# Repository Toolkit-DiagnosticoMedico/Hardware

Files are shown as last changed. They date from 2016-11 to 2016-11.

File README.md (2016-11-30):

# Hardware
Diseño de un Sistema Modular que permitirá medir magnitudes físicas relacionadas a la salud del paciente con la finalidad de
“subirlos la nube” para acceso de diversos servicios. Los parámetros a medir que se manejarán en ésta primera versión serán 
la temperatura, el pulso cardiaco, la presión arterial y la cantidad de la glucosa en la sangre.

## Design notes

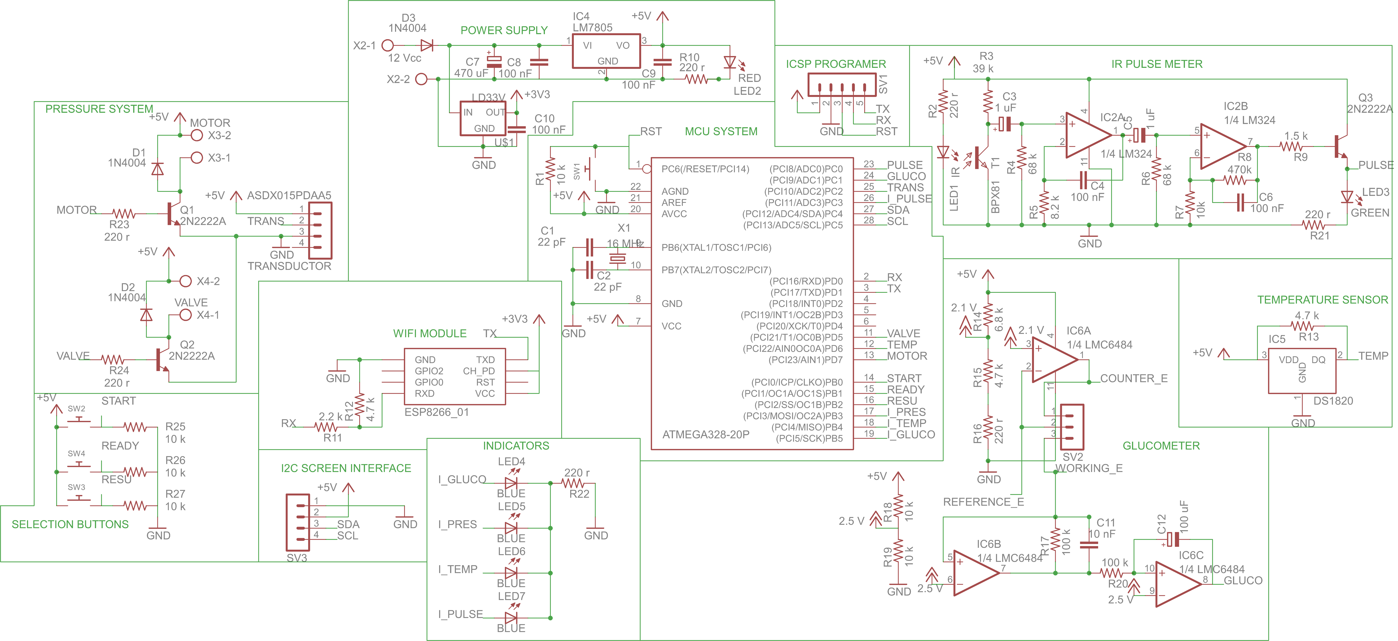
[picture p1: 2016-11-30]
DIAGRAMA.png

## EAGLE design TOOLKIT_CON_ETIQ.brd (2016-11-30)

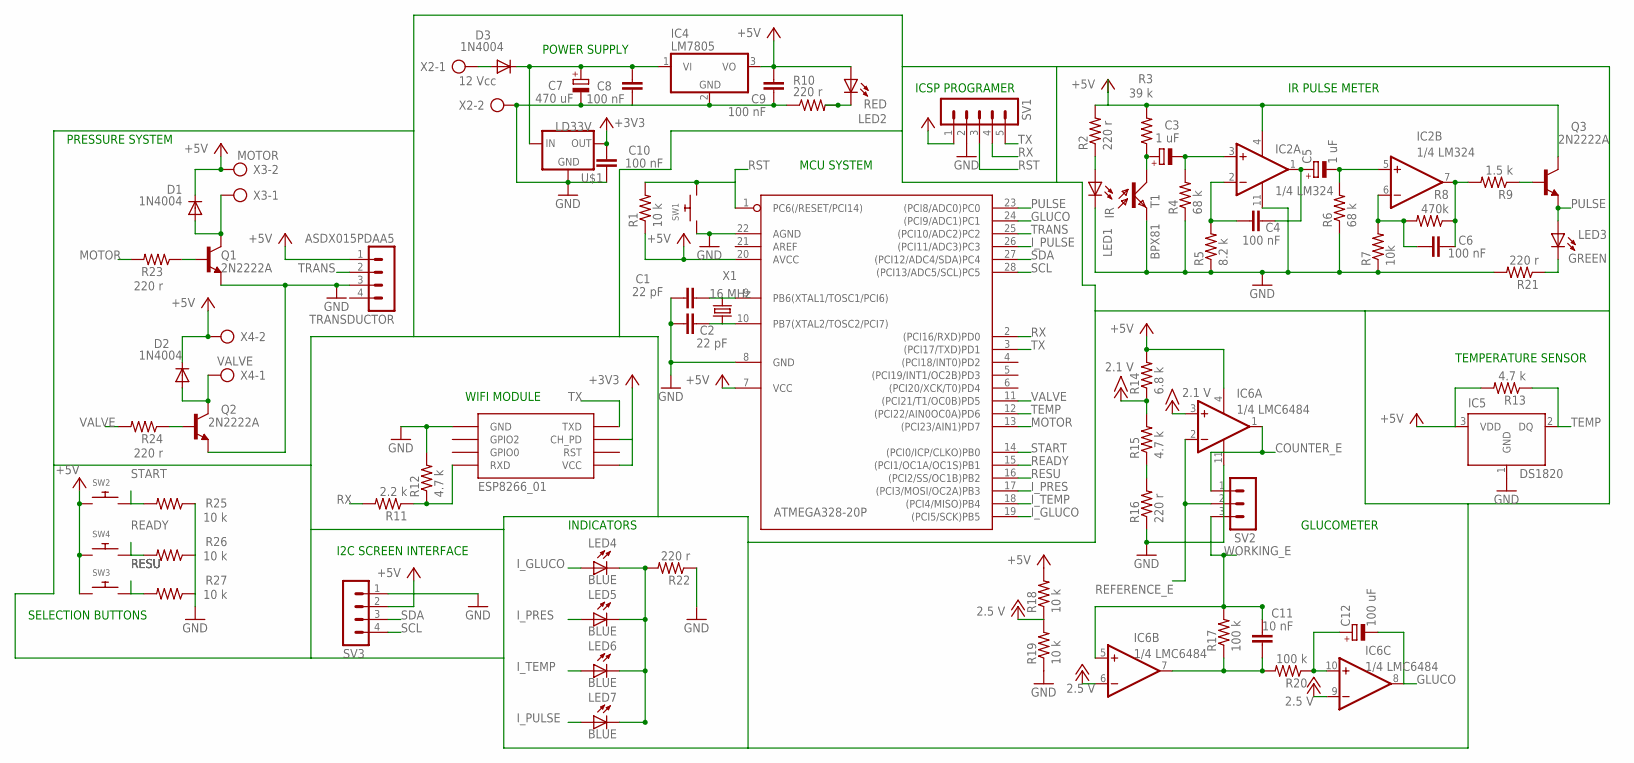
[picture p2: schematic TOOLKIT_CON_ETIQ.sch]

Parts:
C1, C2: 22 pF; C050-024X044
C3, C5: 1 uF; E2,5-6E
C4, C6, C8, C9, C10: 100 nF; C050-025X075
C7: 470 uF; E2,5-6E
C11: 10 nF; C050-025X075
C12: 100 uF; E2,5-6E
D1, D2, D3: 1N4004; DO41-10
IC1: ATMEGA328-20P; DIL28-3
IC2: 1/4 LM324; DIL14
IC4: LM7805; TO220V
IC5: DS1820; TO-92
IC6: 1/4 LMC6484; DIL14
LED1: IR; LED3MM
LED2: RED; LED3MM
LED3: GREEN; LED3MM
LED4, LED5, LED6, LED7: BLUE; LED3MM
Q1, Q2, Q3: 2N2222A; TO92-EBC
R1, R18, R19, R25, R26, R27: 10 k; 0207/10
R2, R10, R16, R21, R22, R23, R24: 220 r; 0207/10
R3: 39 k; 0207/10
R4, R6: 68 k; 0207/10
R5: 8.2 k; 0207/10
R7: 10k; 0207/10
R8: 470k; 0207/10
R9: 1.5 k; 0207/10
R11: 2.2 k; 0207/10
R12, R13, R15: 4.7 k; 0207/10
R14: 6.8 k; 0207/10
R17, R20: 100 k; 0207/10
SV1: MA05-1
SV2: MA03-1
SV3: MA04-1
SW1, SW2, SW3, SW4: SWITCH_PUSHBUTTONEVQ-PE; TACT_PANA-EVQ
T1: BPX81
TRANSDUCTOR: ASDX015PDAA5; MA04-1
U$1: LD33V; LD1117V33
U$2: ESP8266_01; ESP01
X1: 16 MHz; HC18U-V
X2: 12 Vcc; AK500/2
X3: MOTOR; AK500/2
X4: VALVE; AK500/2

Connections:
+3V3: C10.2, U$1.OUT, U$2.CH_PD, U$2.VCC
+12V: IC6.6 (-IN), IC6.9 (-IN), R18.1, R19.2
+15V: IC6.3 (+IN), R14.1, R15.2
COUNTER_E: IC6.1 (OUT), SV2.1
GLUCO: C12.-, IC1.24 ((PCI9/ADC1)PC1), IC6.8 (OUT)
GND: C1.1, C2.1, C7.-, C8.1, C9.1, C10.1, IC1.8 (GND), IC1.22 (AGND), IC2.11 (V-), IC4.2 (GND), IC5.1 (GND), IC6.11 (V-), LED1.K (C), Q1.E, Q2.E, R4.1, R5.1, R6.1, R7.1, R10.1, R12.2, R16.1, R19.1, R21.2, R22.1, R25.1, R26.1, R27.1, SV1.2, SV3.1, SW1.P$1, T1.E, TRANSDUCTOR.3, U$1.GND, U$2.GND, X2.2
I_GLUCO: IC1.19 ((PCI5/SCK)PB5), LED4.A
I_PRES: IC1.17 ((PCI3/MOSI/OC2A)PB3), LED5.A
I_PULSE: IC1.26 ((PCI11/ADC3)PC3), LED7.A
I_TEMP: IC1.18 ((PCI4/MISO)PB4), LED6.A
MOTOR: IC1.13 ((PCI23/AIN1)PD7), R23.2
unnamed: C1.2, IC1.9 (PB6(XTAL1/TOSC1/PCI6)), X1.1
unnamed: C2.2, IC1.10 (PB7(XTAL2/TOSC2/PCI7)), X1.2
unnamed: R11.1, R12.1, U$2.RX (RXD)
unnamed: LED1.A, R2.1
unnamed: C3.+, R3.1, T1.C
unnamed: C3.-, IC2.3 (+IN), R4.2
unnamed: C4.1, IC2.2 (-IN), R5.2
unnamed: C6.1, IC2.6 (-IN), R7.2, R8.2
unnamed: C6.2, IC2.7 (OUT), R8.1, R9.2
unnamed: C4.2, C5.+, IC2.1 (OUT)
unnamed: C5.-, IC2.5 (+IN), R6.2
unnamed: Q3.B, R9.1
unnamed: R15.1, R16.2
unnamed: LED3.K (C), R21.1
unnamed: C7.+, C8.2, D3.C, IC4.1 (VI), U$1.IN
unnamed: LED2.K (C), R10.2
unnamed: LED4.K (C), LED5.K (C), LED6.K (C), LED7.K (C), R22.2
unnamed: C11.1, IC6.7 (OUT), R17.1, R20.2
unnamed: Q1.B, R23.1
unnamed: C12.+, IC6.10 (+IN), R20.1
unnamed: D2.A, Q2.C, X4.1
unnamed: D1.A, Q1.C, X3.1
unnamed: Q2.B, R24.1
unnamed: D3.A, X2.1
PULSE: IC1.23 ((PCI8/ADC0)PC0), LED3.A, Q3.E
READY: IC1.15 ((PCI1/OC1A/OC1S)PB1), R26.2, SW4.P$2
REFERENCE_E: IC6.2 (-IN), SV2.2
RESU: IC1.16 ((PCI2/SS/OC1B)PB2), R27.2, SW3.P$2
RST: IC1.1 (PC6(/RESET/PCI14)), R1.2, SV1.3, SW1.P$2
RX: IC1.2 ((PCI16/RXD)PD0), R11.2, SV1.4
SCL: IC1.28 ((PCI13/ADC5/SCL)PC5), SV3.4
SDA: IC1.27 ((PCI12/ADC4/SDA)PC4), SV3.3
START: IC1.14 ((PCI0/ICP/CLKO)PB0), R25.2, SW2.P$2
TEMP: IC1.12 ((PCI22/AIN0OC0A)PD6), IC5.2 (DQ), R13.1
TRANS: IC1.25 ((PCI10/ADC2)PC2), TRANSDUCTOR.2
TX: IC1.3 ((PCI17/TXD)PD1), SV1.5, U$2.TX (TXD)
VALVE: IC1.11 ((PCI21/T1/OC0B)PD5), R24.2
WORKING_E: C11.2, IC6.5 (+IN), R17.2, SV2.3

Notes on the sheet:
POWER SUPPLY
WIFI MODULE
I2C SCREEN INTERFACE
IR PULSE METER
TEMPERATURE SENSOR
GLUCOMETER
ICSP PROGRAMER
INDICATORS
PRESSURE SYSTEM
MCU SYSTEM
SELECTION BUTTONS

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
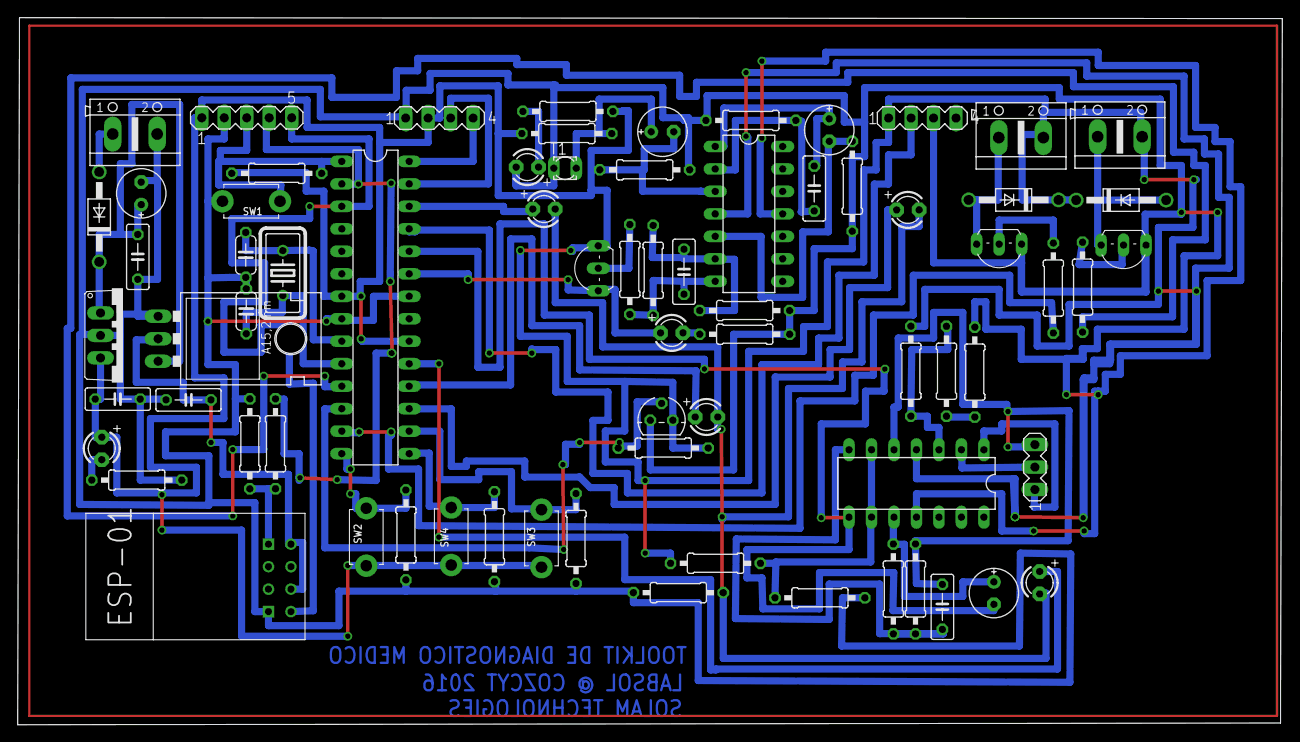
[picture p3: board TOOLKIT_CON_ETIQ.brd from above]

Board: 2 copper layers, 142.9 x 79.9 mm, 72 parts (0 on the bottom side), 51 nets.
